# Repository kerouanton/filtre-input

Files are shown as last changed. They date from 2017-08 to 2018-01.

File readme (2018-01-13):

Ce projet est destiné à tout radioamateur intéressé dans la construction et la mise au point d'un amplificateur 
à base de triode Russe GS35b.
Il s'agit d'une série de filtres en PI commutés (par le biais d'un étage logique genre Arduino ou simplement à l'aide 
d'un commutateur à galette), et qui dispose par défaut de 10 cellules -une par bande.
Le pcb a été conçu pour pouvoir être coupé dans le sens de sa largeur, 
- soit pour n'installer que 6 filtres correspondant aux 6 bandes WARC "old school" (version traditionnelle du filtre TU6B de WD7S)
voir http://home.earthlink.net/~wd7s/TU-6B.htm
- soit, s'il est coupé par son exact milieu, pour que chaque moitié soit montée en "piggy back" afin de pouvoir loger 
le filtre 10 éléments dans un boitier plus court

Nous recommandons vivement que ce filtre soit installé directement dans le boitier de l'amplificateur
plutôt qu'à l'extérieur. 

Le filtre le plus proche de la triode doit si possible être le filtre de la bande la plus haute (6 mètres ou 10 mètres)
Il est également recommandé de monter la capa shunt de ce filtre directement sur la cathode de la lampe et non à son emplacement prévu
sur le pcb.

Pour plus de renseignements, se reporter au Wiki associé
https://github.com/F6ITU/filtre-input/wiki

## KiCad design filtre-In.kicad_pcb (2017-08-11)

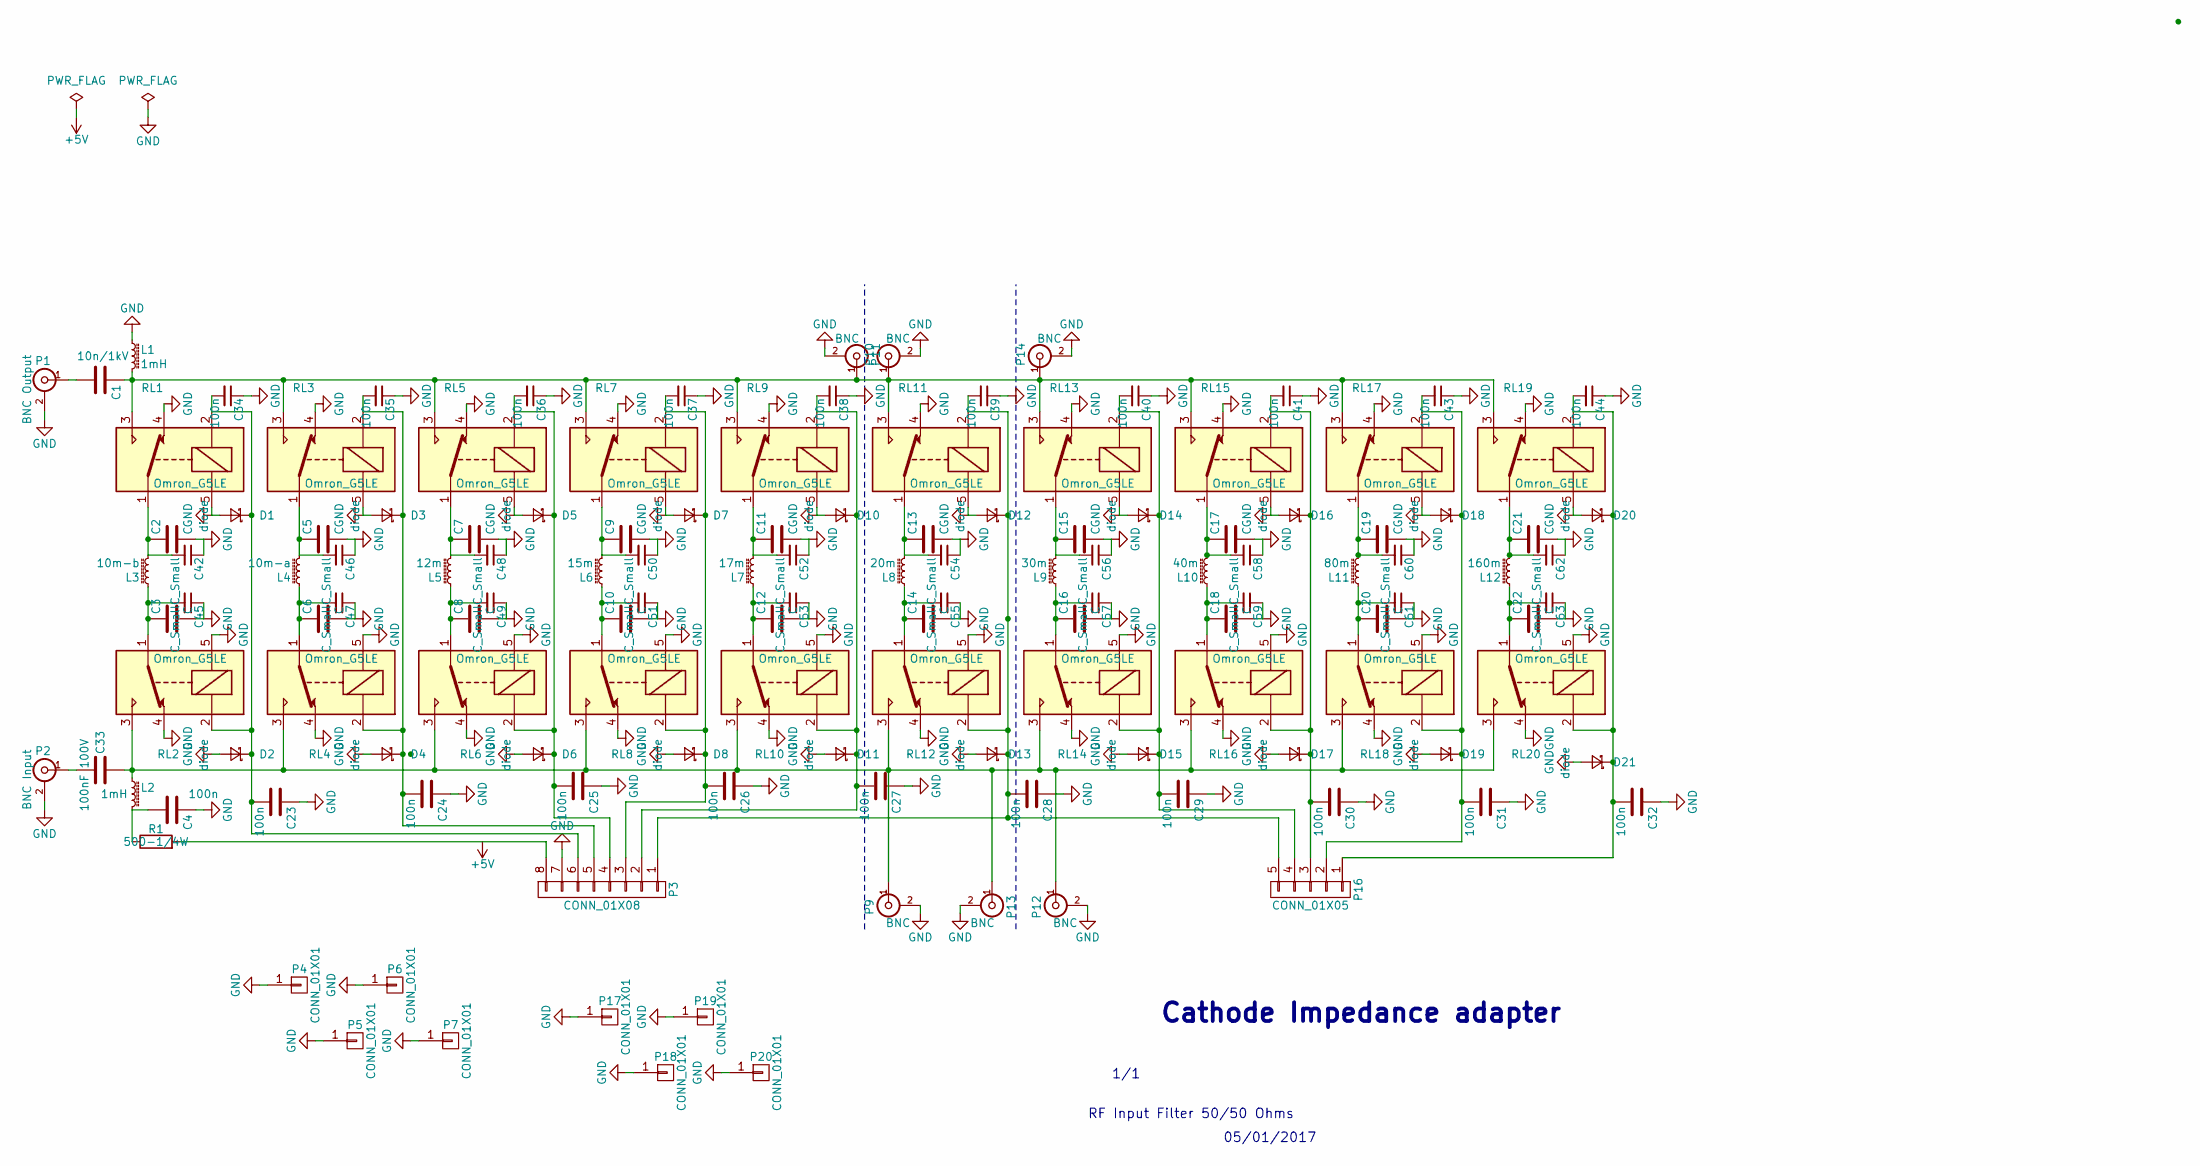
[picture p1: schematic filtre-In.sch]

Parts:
C1: 10n/1kV; silver_mica
C2, C3, C5, C6, C7, C8, C9, C10, C11, C12, C13, C14, C15, C16, C17, C18, C19, C20, C21, C22: C; silver_mica
C4, C23, C24, C25, C26, C27, C28, C29, C30, C31, C32, C34, C35, C36, C37, C38, C39, C40, C41, C43, C44: 100n; C_1206_HandSoldering
C33: 100nF 100V; C_1206_HandSoldering
C42, C45, C46, C47, C48, C49, C50, C51, C52, C53, C54, C55, C56, C57, C58, C59, C60, C61, C62, C63: C_Small; C_1825_HandSoldering
D1, D2, D3, D4, D5, D6, D7, D8, D10, D11, D12, D13, D14, D15, D16, D17, D18, D19, D20, D21: diode; D_SMB_Handsoldering
L1, L2: 1mH; Wurt_1mH
L3: 10m-b; T60_80_V
L4: 10m-a; T60_80_V
L5: 12m; T60_80_V
L6: 15m; T60_80_V
L7: 17m; T60_80_V
L8: 20m; T60_80_V
L9: 30m; T60_80_V
L10: 40m; T60_80_V
L11: 80m; T60_80_V
L12: 160m; T60_80_V
P1: BNC Output; coax_2mm
P2: BNC Input; coax_2mm
P3: CONN_01X08; kk100_22-23-2081
P4, P5, P6, P7, P17, P18, P19, P20: CONN_01X01; 1pin
P9, P10, P11, P12, P13, P14: BNC; coax_2mm
P16: CONN_01X05; kk100_22-23-2051
R1: 500-1/4W; R_Axial_DIN0411_L9.9mm_D3.6mm_P12.70mm_Horizontal
RL1, RL2, RL3, RL4, RL5, RL6, RL7, RL8, RL9, RL10, RL11, RL12, RL13, RL14, RL15, RL16, RL17, RL18, RL19, RL20: Omron_G5LE

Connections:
GND: C2.2, C3.2, C4.1, C5.2, C6.2, C7.2, C8.2, C9.2, C10.2, C11.2, C12.2, C13.2, C14.2, C15.2, C16.2, C17.2, C18.2, C19.2, C20.2, C21.2, C22.2, C23.1, C24.1, C25.1, C26.1, C27.1, C28.1, C29.1, C30.1, C31.1, C32.1, C34.1, C35.1, C36.1, C37.1, C38.1, C39.1, C40.1, C41.1, C42.1, C43.1, C44.1, C45.1, C46.1, C47.1, C48.1, C49.1, C50.1, C51.1, C52.1, C53.1, C54.1, C55.1, C56.1, C57.1, C58.1, C59.1, C60.1, C61.1, C62.1, C63.1, D1.2 (A), D2.2 (A), D3.2 (A), D4.2 (A), D5.2 (A), D6.2 (A), D7.2 (A), D8.2 (A), D10.2 (A), D11.2 (A), D12.2 (A), D13.2 (A), D14.2 (A), D15.2 (A), D16.2 (A), D17.2 (A), D18.2 (A), D19.2 (A), D20.2 (A), D21.2 (A), L1.1, P1.2 (Ext), P2.2 (Ext), P3.7, P4.1, P5.1, P6.1, P7.1, P9.2 (Ext), P10.2 (Ext), P11.2 (Ext), P12.2 (Ext), P13.2 (Ext), P14.2 (Ext), P17.1, P18.1, P19.1, P20.1, RL1.4, RL1.5, RL2.4, RL2.5, RL3.4, RL3.5, RL4.4, RL4.5, RL5.4, RL5.5, RL6.4, RL6.5, RL7.4, RL7.5, RL8.4, RL8.5, RL9.4, RL9.5, RL10.4, RL10.5, RL11.4, RL11.5, RL12.4, RL12.5, RL13.4, RL13.5, RL14.4, RL14.5, RL15.4, RL15.5, RL16.4, RL16.5, RL17.4, RL17.5, RL18.4, RL18.5, RL19.4, RL19.5, RL20.4, RL20.5
unnamed: C1.1, L1.2, P10.1 (In), P11.1 (In), P14.1 (In), RL1.3, RL3.3, RL5.3, RL7.3, RL9.3, RL11.3, RL13.3, RL15.3, RL17.3, RL19.3
unnamed: C1.2, P1.1 (In)
unnamed: C2.1, C42.2, L3.2, RL1.1
unnamed: C3.1, C45.2, L3.1, RL2.1
unnamed: C4.2, L2.2, R1.1
unnamed: C10.1, C51.2, L6.1, RL8.1
unnamed: C11.1, C52.2, L7.2, RL9.1
unnamed: C12.1, C53.2, L7.1, RL10.1
unnamed: C13.1, C54.2, L8.2, RL11.1
unnamed: C14.1, C55.2, L8.1, RL12.1
unnamed: C15.1, C56.2, L9.2, RL13.1
unnamed: C16.1, C57.2, L9.1, RL14.1
unnamed: C17.1, C58.2, L10.2, RL15.1
unnamed: C18.1, C59.2, L10.1, RL16.1
unnamed: C19.1, C60.2, L11.2, RL17.1
unnamed: C20.1, C61.2, L11.1, RL18.1
unnamed: C21.1, C62.2, L12.2, RL19.1
unnamed: C22.1, C63.2, L12.1, RL20.1
unnamed: C23.2, C34.2, D1.1 (K), D2.1 (K), P3.6, RL1.2, RL2.2
unnamed: C24.2, C35.2, D3.1 (K), D4.1 (K), P3.5, RL3.2, RL4.2
unnamed: C25.2, C36.2, D5.1 (K), D6.1 (K), P3.4, RL5.2, RL6.2
unnamed: C26.2, C37.2, D7.1 (K), D8.1 (K), P3.3, RL7.2, RL8.2
unnamed: C27.2, C38.2, D10.1 (K), D11.1 (K), P3.2, RL9.2, RL10.2
unnamed: C28.2, C39.2, D12.1 (K), D13.1 (K), P3.1, P16.5, RL11.2, RL12.2
unnamed: C29.2, C40.2, D14.1 (K), D15.1 (K), P16.4, RL13.2, RL14.2
unnamed: C30.2, C41.2, D16.1 (K), D17.1 (K), P16.3, RL15.2, RL16.2
unnamed: C31.2, C43.2, D18.1 (K), D19.1 (K), P16.2, RL17.2, RL18.2
unnamed: C32.2, C44.2, D20.1 (K), D21.1 (K), P16.1, RL19.2, RL20.2
unnamed: C33.1, L2.1, P9.1 (In), P12.1 (In), P13.1 (In), RL2.3, RL4.3, RL6.3, RL8.3, RL10.3, RL12.3, RL14.3, RL16.3, RL18.3, RL20.3
unnamed: C33.2, P2.1 (In)
unnamed: C5.1, C46.2, L4.2, RL3.1
unnamed: C6.1, C47.2, L4.1, RL4.1
unnamed: C7.1, C48.2, L5.2, RL5.1
unnamed: C8.1, C49.2, L5.1, RL6.1
unnamed: C9.1, C50.2, L6.2, RL7.1
unnamed: P3.8, R1.2

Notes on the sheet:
RF Input Filter 50/50 Ohms
1/1
05/01/2017
Cathode Impedance adapter

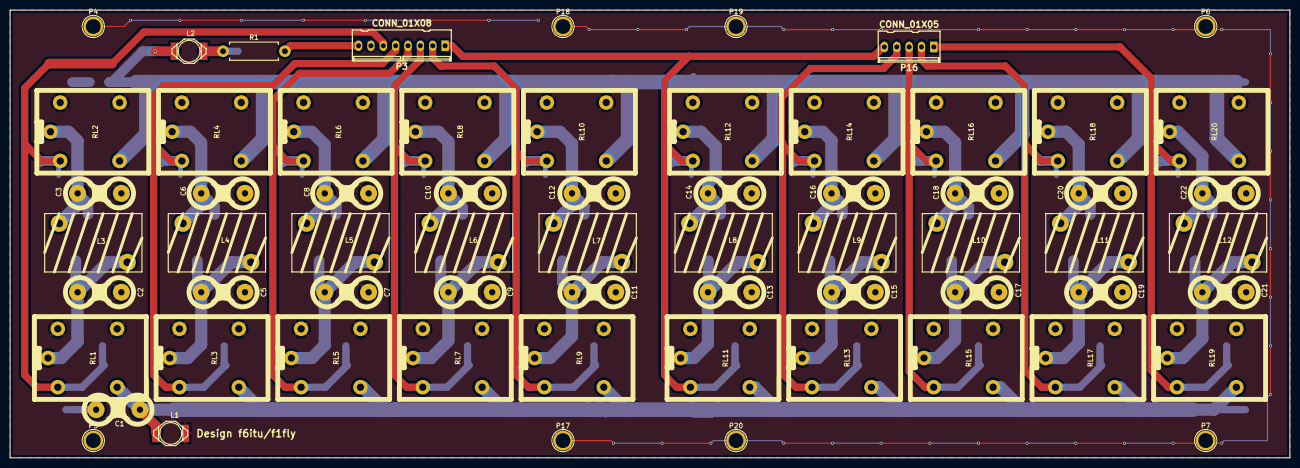
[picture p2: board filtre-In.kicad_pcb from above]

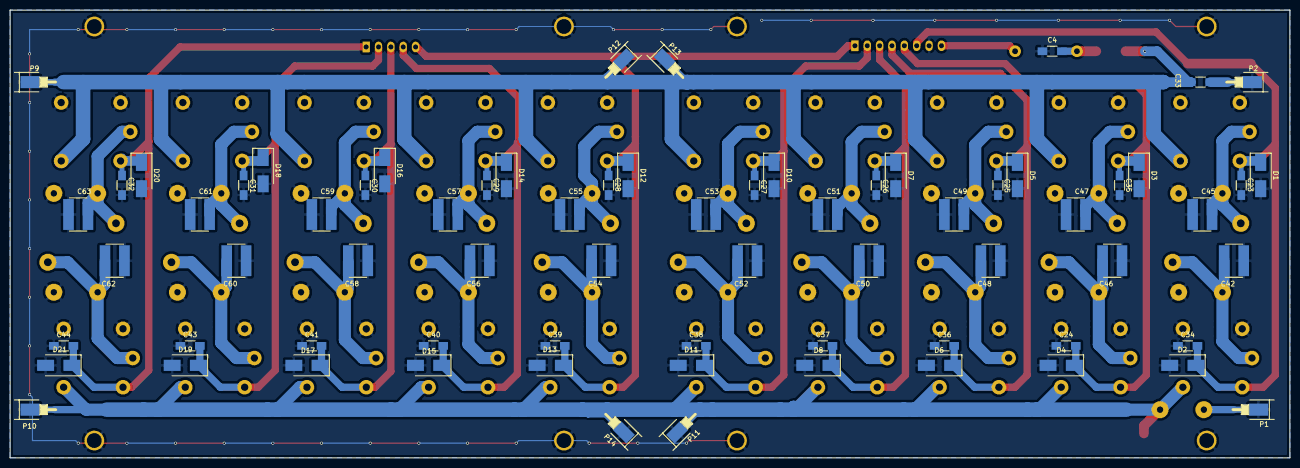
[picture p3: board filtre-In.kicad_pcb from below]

Board: 2 copper layers, 263.0 x 92.0 mm, 134 parts (70 on the bottom side), 37 nets.

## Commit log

2017-01-20 filtre input premier jet
    [filtre-In.kicad_pcb, filtre-In.sch]
2017-01-21 version avec formes 3D, sans condos ATC
    [filtre-In.kicad_pcb]
2017-01-22 version CAO finale, a priori bonne pour la prod
    [filtre-In.kicad_pcb, filtre-In.sch]
2017-01-31 add new footprint/module
2017-02-01 ajout gerber, modif bias
    [filtre-In-B.Cu.gbr, filtre-In-B.Mask.gbr, filtre-In-B.Paste.gbr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]
2017-05-02 version finale gravee
    [filtre-In-B.Cu.gbl, filtre-In-B.Mask.gbs, filtre-In-B.Paste.gbp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]
2017-06-12 release from June 12 2017, debugged and checked
    [filtre-In.kicad_pcb, filtre-In.sch]
2017-08-11 changed relay pinout, changed ATC-B footprint
    [filtre-In-B.Cu.gbl, filtre-In-B.Mask.gbs, filtre-In-B.Paste.gbp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]
